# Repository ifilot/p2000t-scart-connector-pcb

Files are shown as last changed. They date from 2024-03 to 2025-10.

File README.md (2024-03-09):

# P2000T SCART adapter plate

Small four-layer PCB to interface the six wires of the RGBS port with a 
SCART connector.

## Purpose

To interface a P2000T with a SCART-compatible monitor or television, a couple
of resistors need to be placed. This PCB accommodates the resistors in a small
0805 form factor and allows for a sturdy connection with the SCART connector.

> **Warning**
> The SCART interface requires a **non-inverted** SYNC signal from the P2000T. Whether
> your P2000T outputs an inverted or non-inverted SYNC signal can be controlled
> by means of placing a solder joint on the mainboard of your P2000T. For more
> information, please consult [this website](https://www.philips-p2000t.nl/hardware/videoport.html#regular-or-inverted-sync-signal).

## PCBs

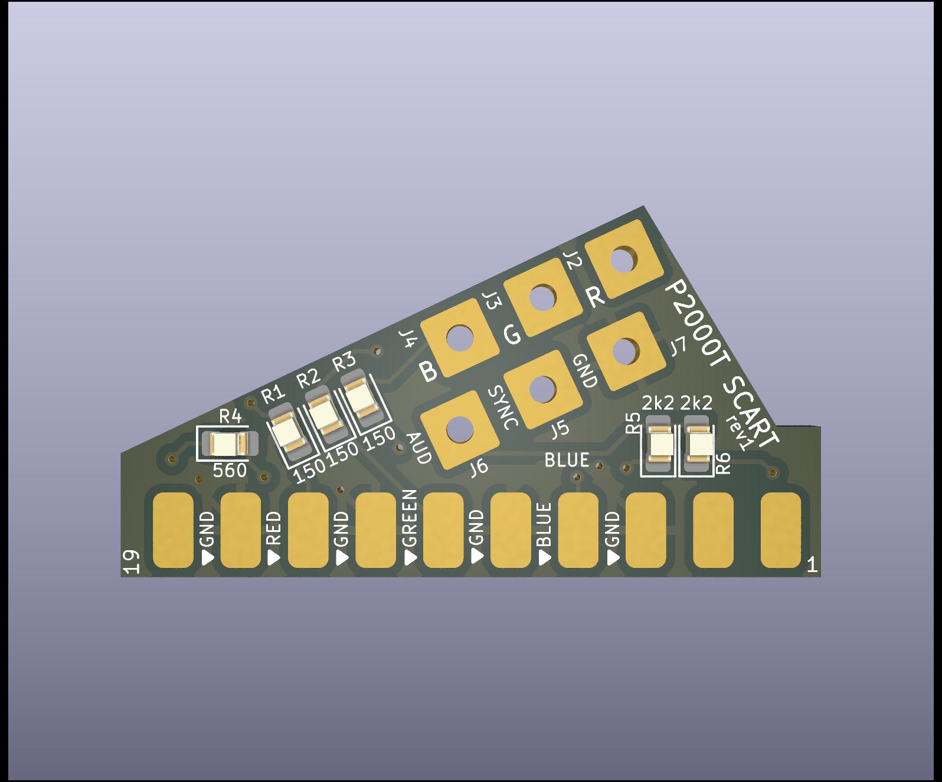
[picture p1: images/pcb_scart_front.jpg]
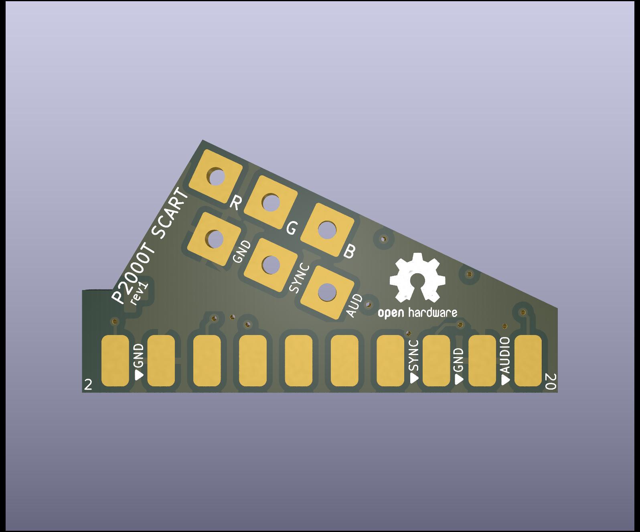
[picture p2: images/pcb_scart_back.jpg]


## Cable assembly

1. Solder the 0805 resistors onto the PCB.
2. Solder the wires onto the PCB and in turn solder the PCB to the SCART connector.
3. Place the SCART connector into its enclosure and close it.
4. Connect the wires to their corresponding terminals in the DIN6 connector.

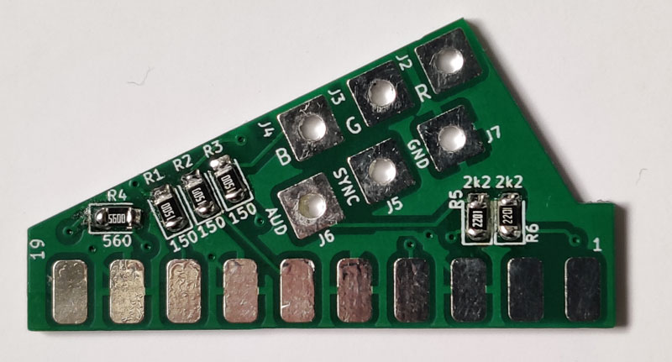
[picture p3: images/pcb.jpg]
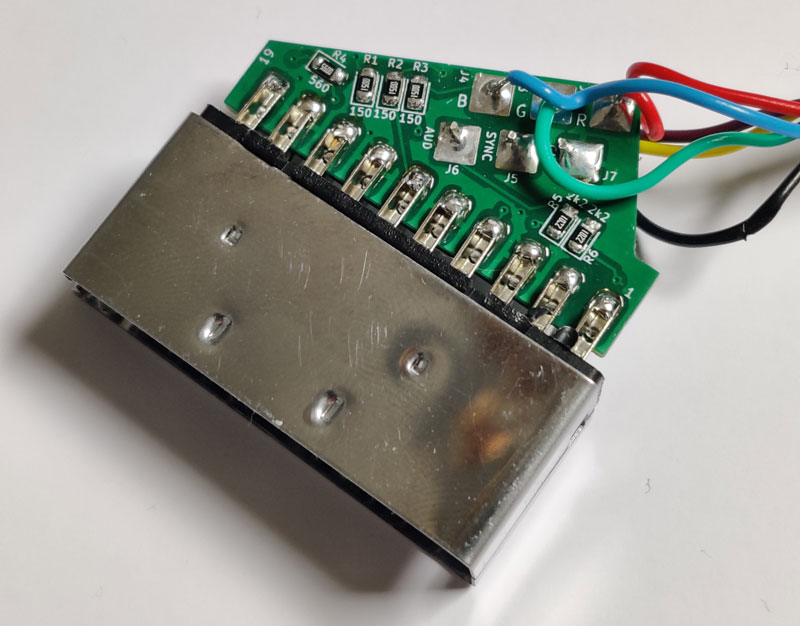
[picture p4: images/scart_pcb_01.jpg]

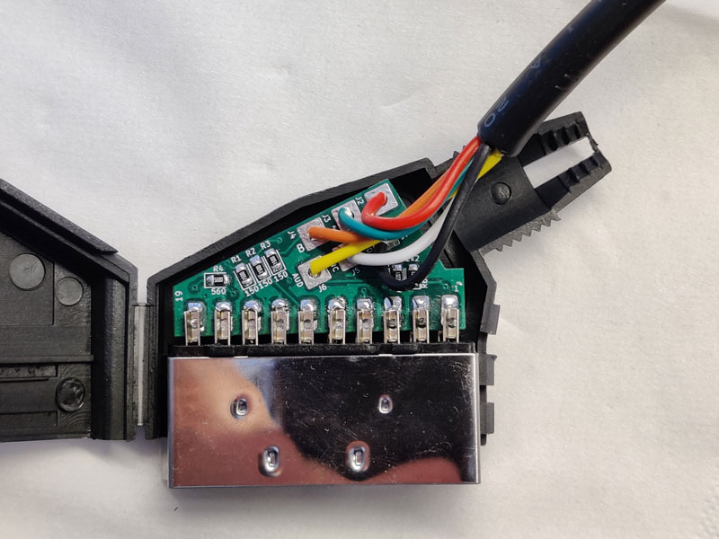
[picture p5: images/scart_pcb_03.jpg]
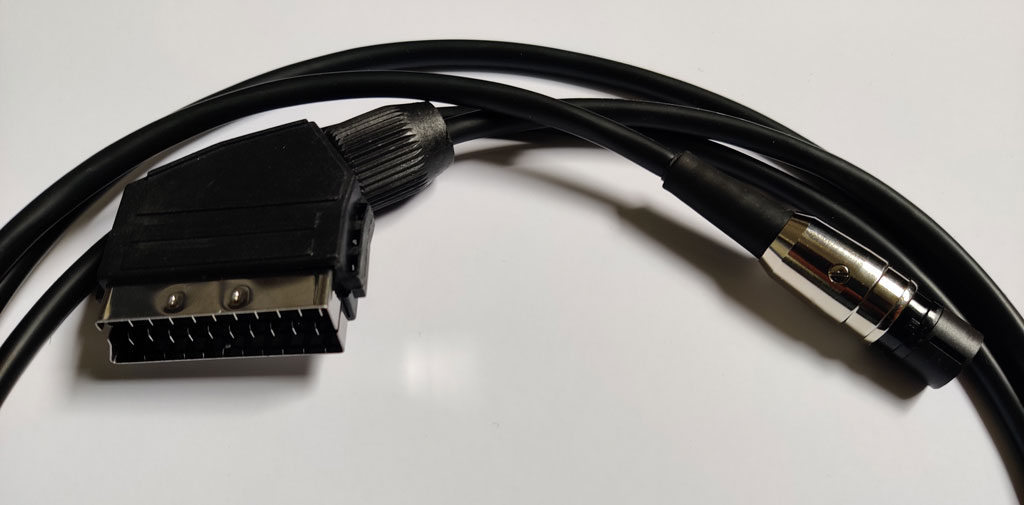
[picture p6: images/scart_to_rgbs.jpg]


The signals on the RBGS, as seen by looking into the female socket on the back
side of the P2000T, is provided below. **Note that the colors in the image below
do not necessarily correspond to the wire colors as shown above.**

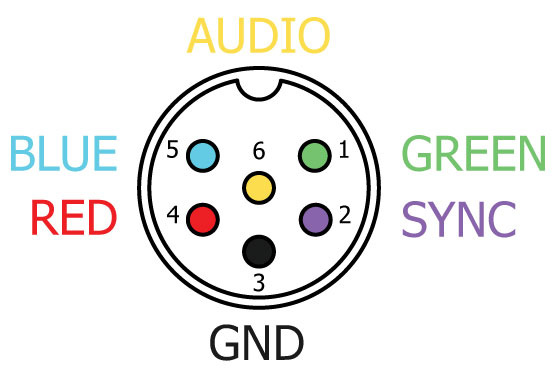
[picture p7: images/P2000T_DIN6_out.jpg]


In the image below, a P2000T is connected to a modern flat-screen television
with a SCART interface. As can be seen, the video quality is fairly good.
Note that different televisions use different soft- and hardware implementations
to convert the analog SCART signals to an image. The quality on your television
or monitor may vary.

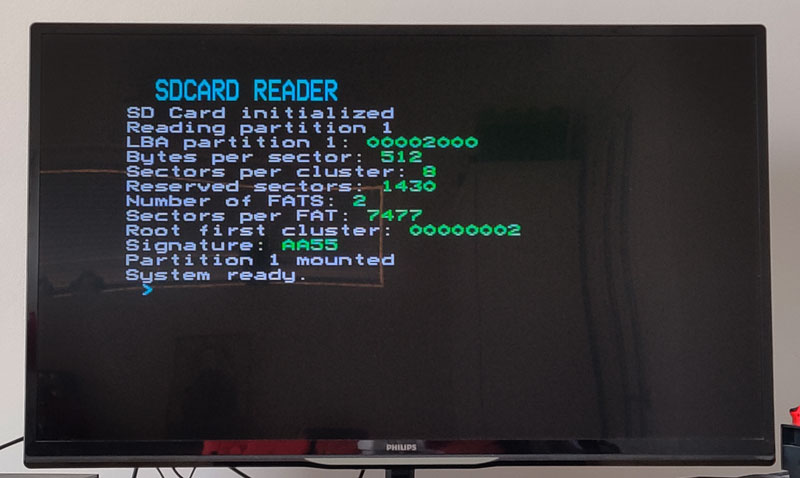
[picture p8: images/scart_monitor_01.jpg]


## Bill of materials

* 2 x 2.2kΩ 0805 resistors
* 3 x 150Ω 0805 resistors
* 1 x 560Ω 0805 resistor
* 1 x SCART connector
* 1 x DIN6 male connector
* 6-wire cable

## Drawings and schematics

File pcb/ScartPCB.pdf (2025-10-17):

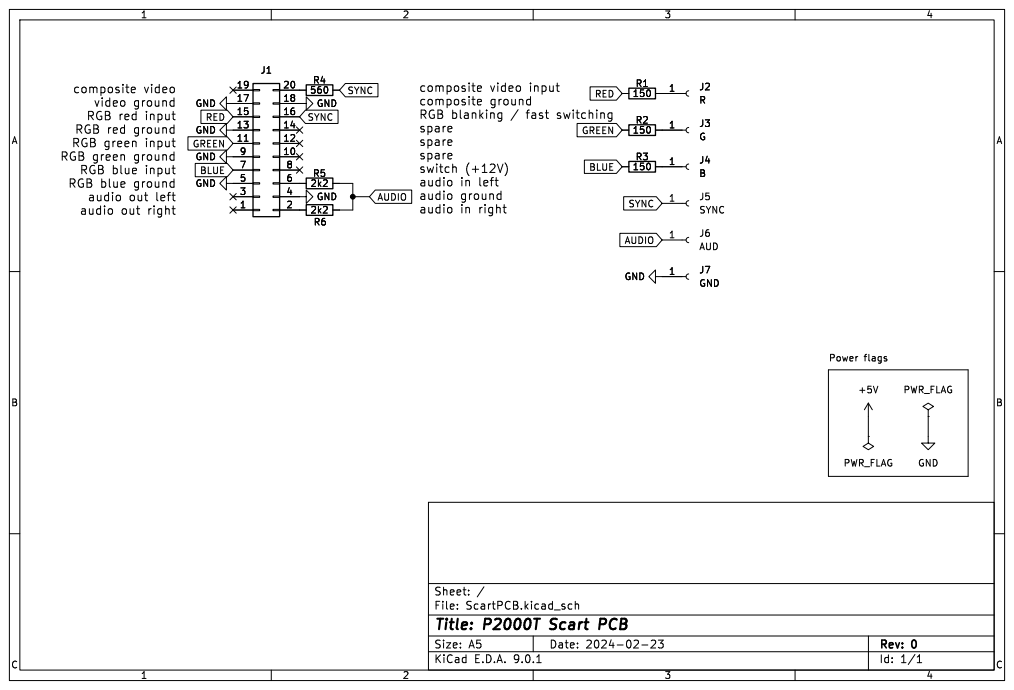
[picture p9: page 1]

File: ScartPCB.kicad_sch Sheet: / GND

Id: 1/1 Title: P2000T Scart PCB

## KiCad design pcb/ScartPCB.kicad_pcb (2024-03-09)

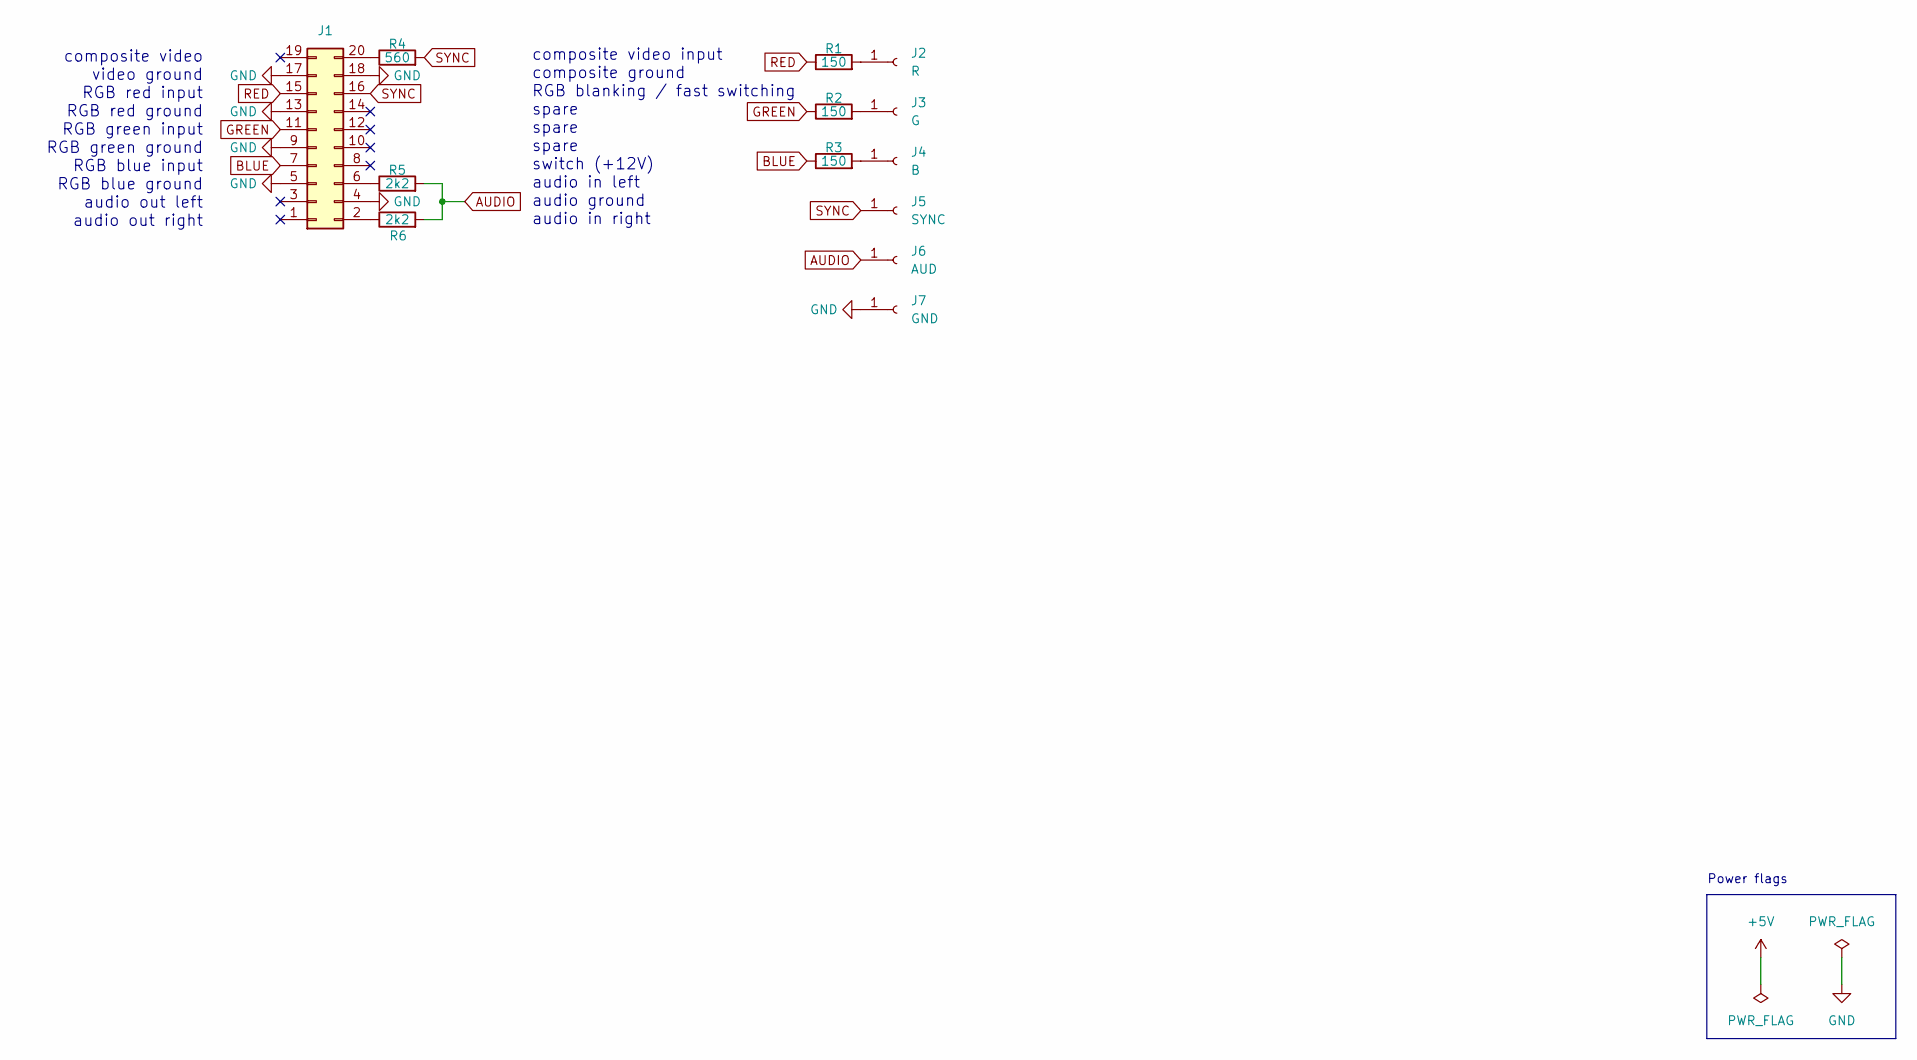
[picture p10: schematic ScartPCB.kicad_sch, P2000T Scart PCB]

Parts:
J1: Conn_02x10_Odd_Even; SCART
J2: R; SolderWire-0.75sqmm_1x01_D1.25mm_OD3.5mm
J3: G; SolderWire-0.75sqmm_1x01_D1.25mm_OD3.5mm
J4: B; SolderWire-0.75sqmm_1x01_D1.25mm_OD3.5mm
J5: SYNC; SolderWire-0.75sqmm_1x01_D1.25mm_OD3.5mm
J6: AUD; SolderWire-0.75sqmm_1x01_D1.25mm_OD3.5mm
J7: GND; SolderWire-0.75sqmm_1x01_D1.25mm_OD3.5mm
R1, R2, R3: 150; LED_0805_2012Metric_Pad1.15x1.40mm_HandSolder
R4: 560; LED_0805_2012Metric_Pad1.15x1.40mm_HandSolder
R5, R6: 2k2; LED_0805_2012Metric_Pad1.15x1.40mm_HandSolder

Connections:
AUDIO: J6.1, R5.2, R6.2
BLUE: J1.7, R3.1
GND: J1.4, J1.5, J1.9, J1.13, J1.17, J1.18, J7.1
GREEN: J1.11, R2.1
unnamed: J1.2, R6.1
unnamed: J1.6, R5.1
unnamed: J1.20, R4.1
unnamed: J2.1, R1.2
unnamed: J3.1, R2.2
unnamed: J4.1, R3.2
RED: J1.15, R1.1
SYNC: J1.16, J5.1, R4.2

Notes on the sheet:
Power flags
composite video input composite ground RGB blanking / fast switching spare spare spare switch (+12V) audio in left audio ground audio in right
composite video video ground RGB red input RGB red ground RGB green input RGB green ground RGB blue input RGB blue ground audio out left audio out right

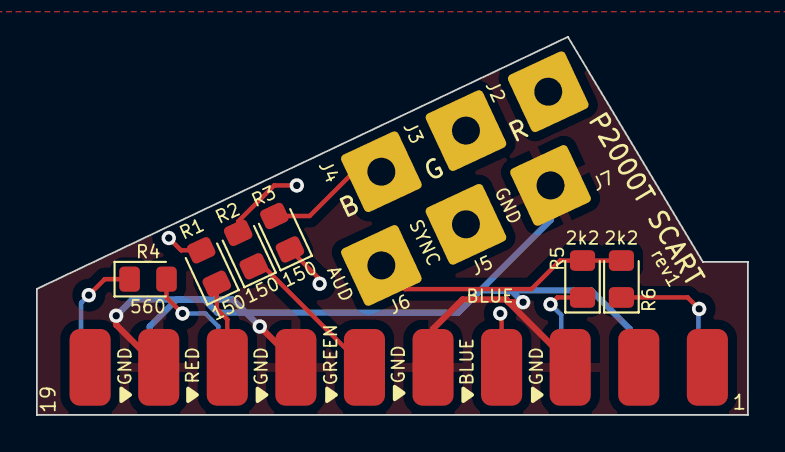
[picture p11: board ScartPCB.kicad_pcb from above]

Board: 4 copper layers, 39.5 x 21.0 mm, 14 parts (1 on the bottom side), 12 nets.

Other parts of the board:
LOGO1: OSHW-Logo2_7.3x6mm_SilkScreen

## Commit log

2024-03-09 Revising PCB
    [ScartPCB-B_Cu.gbr, ScartPCB-B_Mask.gbr, ScartPCB-B_Paste.gbr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]
2025-10-17 Adding schematic PDF
    [ScartPCB.kicad_sch]
